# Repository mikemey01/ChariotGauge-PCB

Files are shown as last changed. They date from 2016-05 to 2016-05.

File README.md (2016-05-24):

# ChariotGauge-PCB
All of the gerber files for creating a Chariot Gauge PCB controller yourself.




# Build Your Own
The latest iteration of the controller is in the Version 2 folder. These are all of the gerber files needed to build your own controller from any PCB MFG. The chariotgaugev2.zip contains only the necessary files that any PCB mfg would need.

I use and recommend Advanced Circuits.

Steps for assembling the controller can be found here: https://www.chariotgauge.com/install-guide-diy/

# Modify
If you want to modify the PCB I've included the board and schematic files from Eagle CAD. You'll need to install Eagle CAD to view/edit the schematics.

# Chariot Gauge DIY
There are three parts to the Chariot Gauge project, this is the PCB repo:
* [Chariot Gauge Controller Firmware](https://github.com/mikemey01/ChariotGauge-Firmware)
* [Chariot Gauge Controller](https://github.com/mikemey01/ChariotGauge-PCB)
* [Chariot Gauge Android App](https://github.com/mikemey01/ChariotGaugeAndroid), or [Chariot Gauge iOS App](https://github.com/mikemey01/ChariotGaugeiOS)

# License

MIT License

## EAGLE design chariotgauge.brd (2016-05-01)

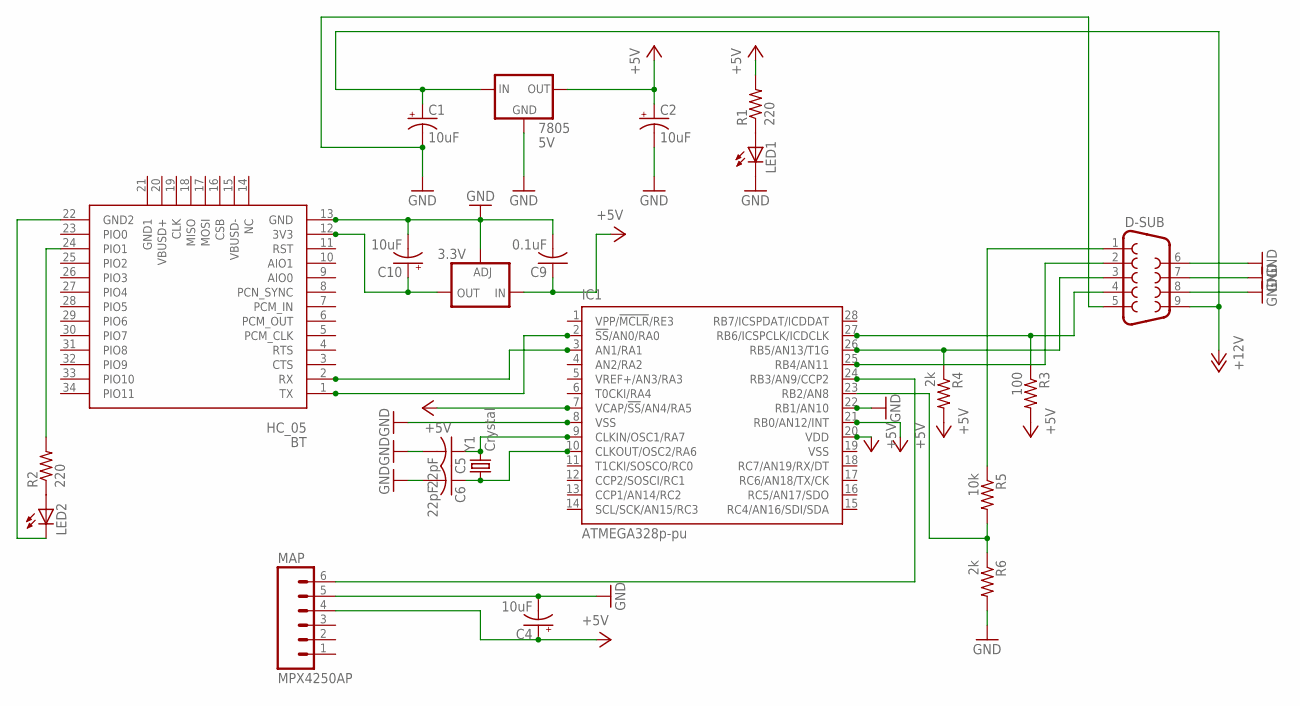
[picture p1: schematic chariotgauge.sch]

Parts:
3.3V: LM317TL; 317TL
7805: 5V; 78XXL
BT: HC_05; BLUETOOTH_SMD
C1, C2, C4, C10: 10uF; CPOL-RADIAL-10UF-25V
C5, C6: 22pF; C025-025X050
C9: 0.1uF; C025-025X050
D-SUB: DB9FEMALE; DB9
IC1: ATMEGA328p-pu; DIL28-3
LED1, LED2: LED5MM
MAP: MPX4250AP; 1X06_LONGPADS
R1, R2: 220; 0204/7
R3: 100; 0204/7
R4, R6: 2k; 0204/7
R5: 10k; 0204/7
Y1: Crystal; HC49US

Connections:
+5V: 3.3V.3 (IN), 7805.OUT, C2.1 (+), C4.1 (+), C9.1, IC1.7 (VCAP/!SS!/AN4/RA5), IC1.20 (VDD), IC1.21 (RB0/AN12/INT), MAP.4, R1.2, R3.2, R4.2
+12V: 7805.IN, C1.1 (+), D-SUB.9
GND: 3.3V.1 (ADJ), 7805.GND, BT.13 (GND), C1.2 (-), C2.2 (-), C4.2 (-), C5.2, C6.2, C9.2, C10.2 (-), D-SUB.5, D-SUB.6, D-SUB.7, D-SUB.8, IC1.8 (VSS), IC1.22 (RB1/AN10), LED1.K (C), MAP.5, R6.2
unnamed: LED1.A, R1.1
unnamed: IC1.24 (RB3/AN9/CCP2), MAP.6
unnamed: D-SUB.2, IC1.25 (RB4/AN11)
unnamed: BT.1 (TX), IC1.2 (!SS!/AN0/RA0)
unnamed: D-SUB.3, IC1.26 (RB5/AN13/T1G), R4.1
unnamed: BT.24 (PIO1), R2.2
unnamed: D-SUB.4, IC1.27 (RB6/ICSPCLK/ICDCLK), R3.1
unnamed: BT.2 (RX), IC1.3 (AN1/RA1)
unnamed: C5.1, IC1.9 (CLKIN/OSC1/RA7), Y1.2
unnamed: C6.1, IC1.10 (CLKOUT/OSC2/RA6), Y1.1
unnamed: LED2.A, R2.1
unnamed: 3.3V.2 (OUT), BT.12 (3V3), C10.1 (+)
unnamed: D-SUB.1, R5.1
unnamed: BT.22 (GND2), LED2.K (C)
unnamed: IC1.23 (RB2/AN8), R5.2, R6.1
VSS: IC1.19 (VSS)

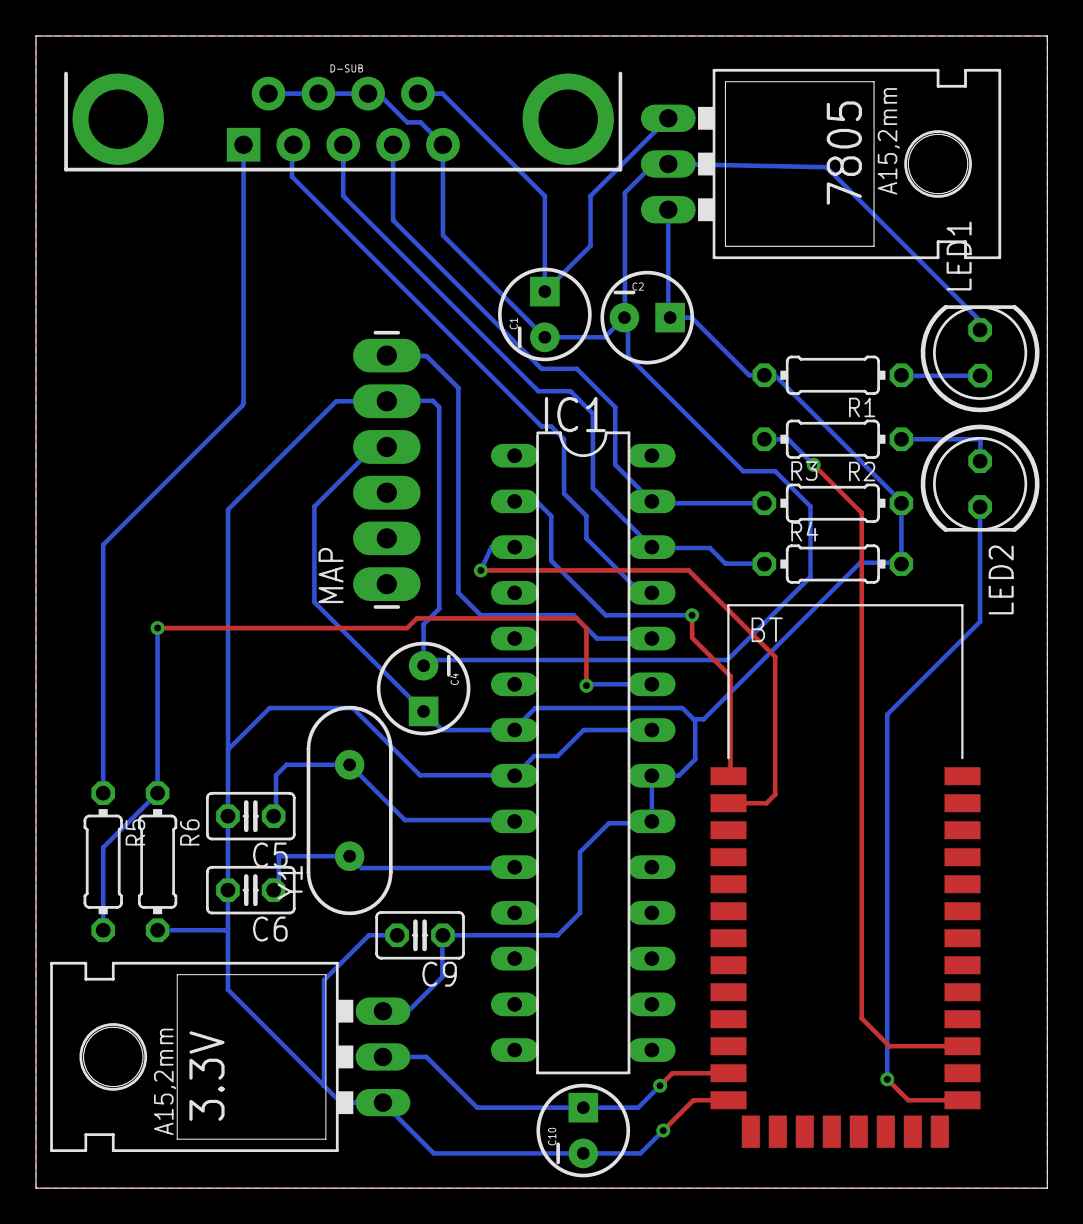
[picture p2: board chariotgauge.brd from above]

Board: 2 copper layers, 56.2 x 64.0 mm, 22 parts (0 on the bottom side), 18 nets.

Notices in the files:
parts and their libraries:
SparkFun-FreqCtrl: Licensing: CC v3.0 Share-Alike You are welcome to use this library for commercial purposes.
